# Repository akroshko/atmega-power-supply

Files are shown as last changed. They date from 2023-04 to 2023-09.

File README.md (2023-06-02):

A Variable-Voltage Constant-Current ATMega-based Power Supply
=============================================================

This project is a challenge to myself to build the best
variable-voltage constant-current power supply I could based on
ubiquitous components such as the LM317 voltage regulator, LM358 or
ATMega328 microcontroller.

The design is loosely based off of
[https://www.youtube.com/playlist?list=PLBF35875F73B5C9B5](https://www.youtube.com/playlist?list=PLBF35875F73B5C9B5)
by EEVblog.  However, it uses components I cannot obtain such as the
LT3080.

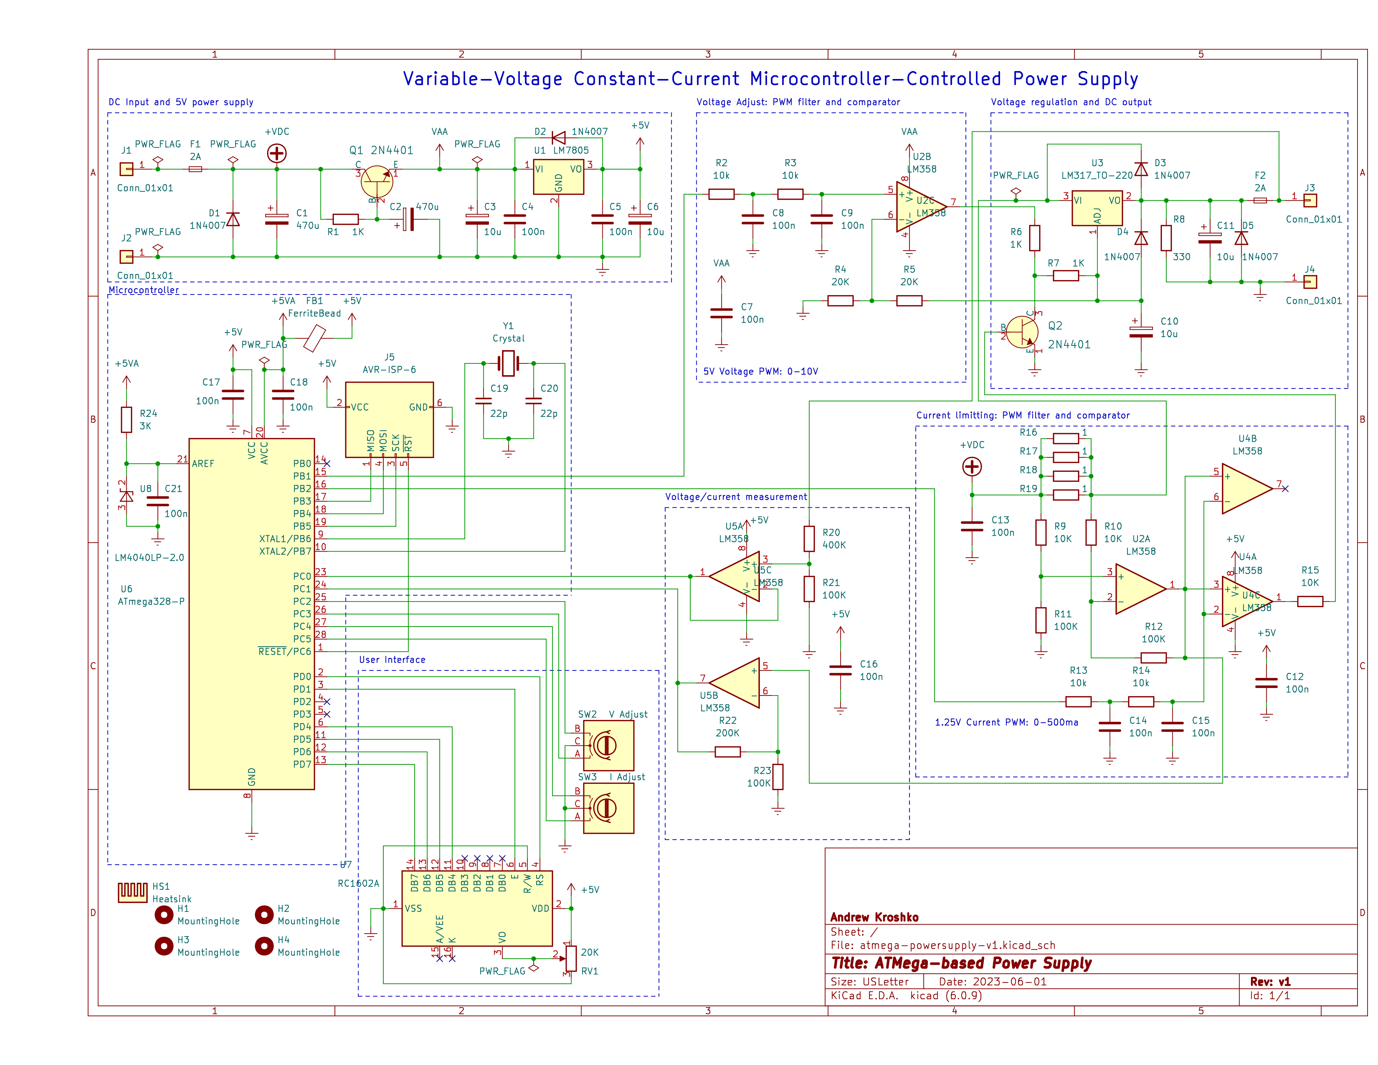
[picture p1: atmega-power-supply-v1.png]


# Things to do

I wouldn't recommend building it yourself quite yet.  There are some
issues with this design and there will be a version 1.1
at some point.

- add a photo of my prototype
- test prototype under different loads
- add a model to calibrate to in software
- use an easier-to-get LCD display
- add a bill of materials

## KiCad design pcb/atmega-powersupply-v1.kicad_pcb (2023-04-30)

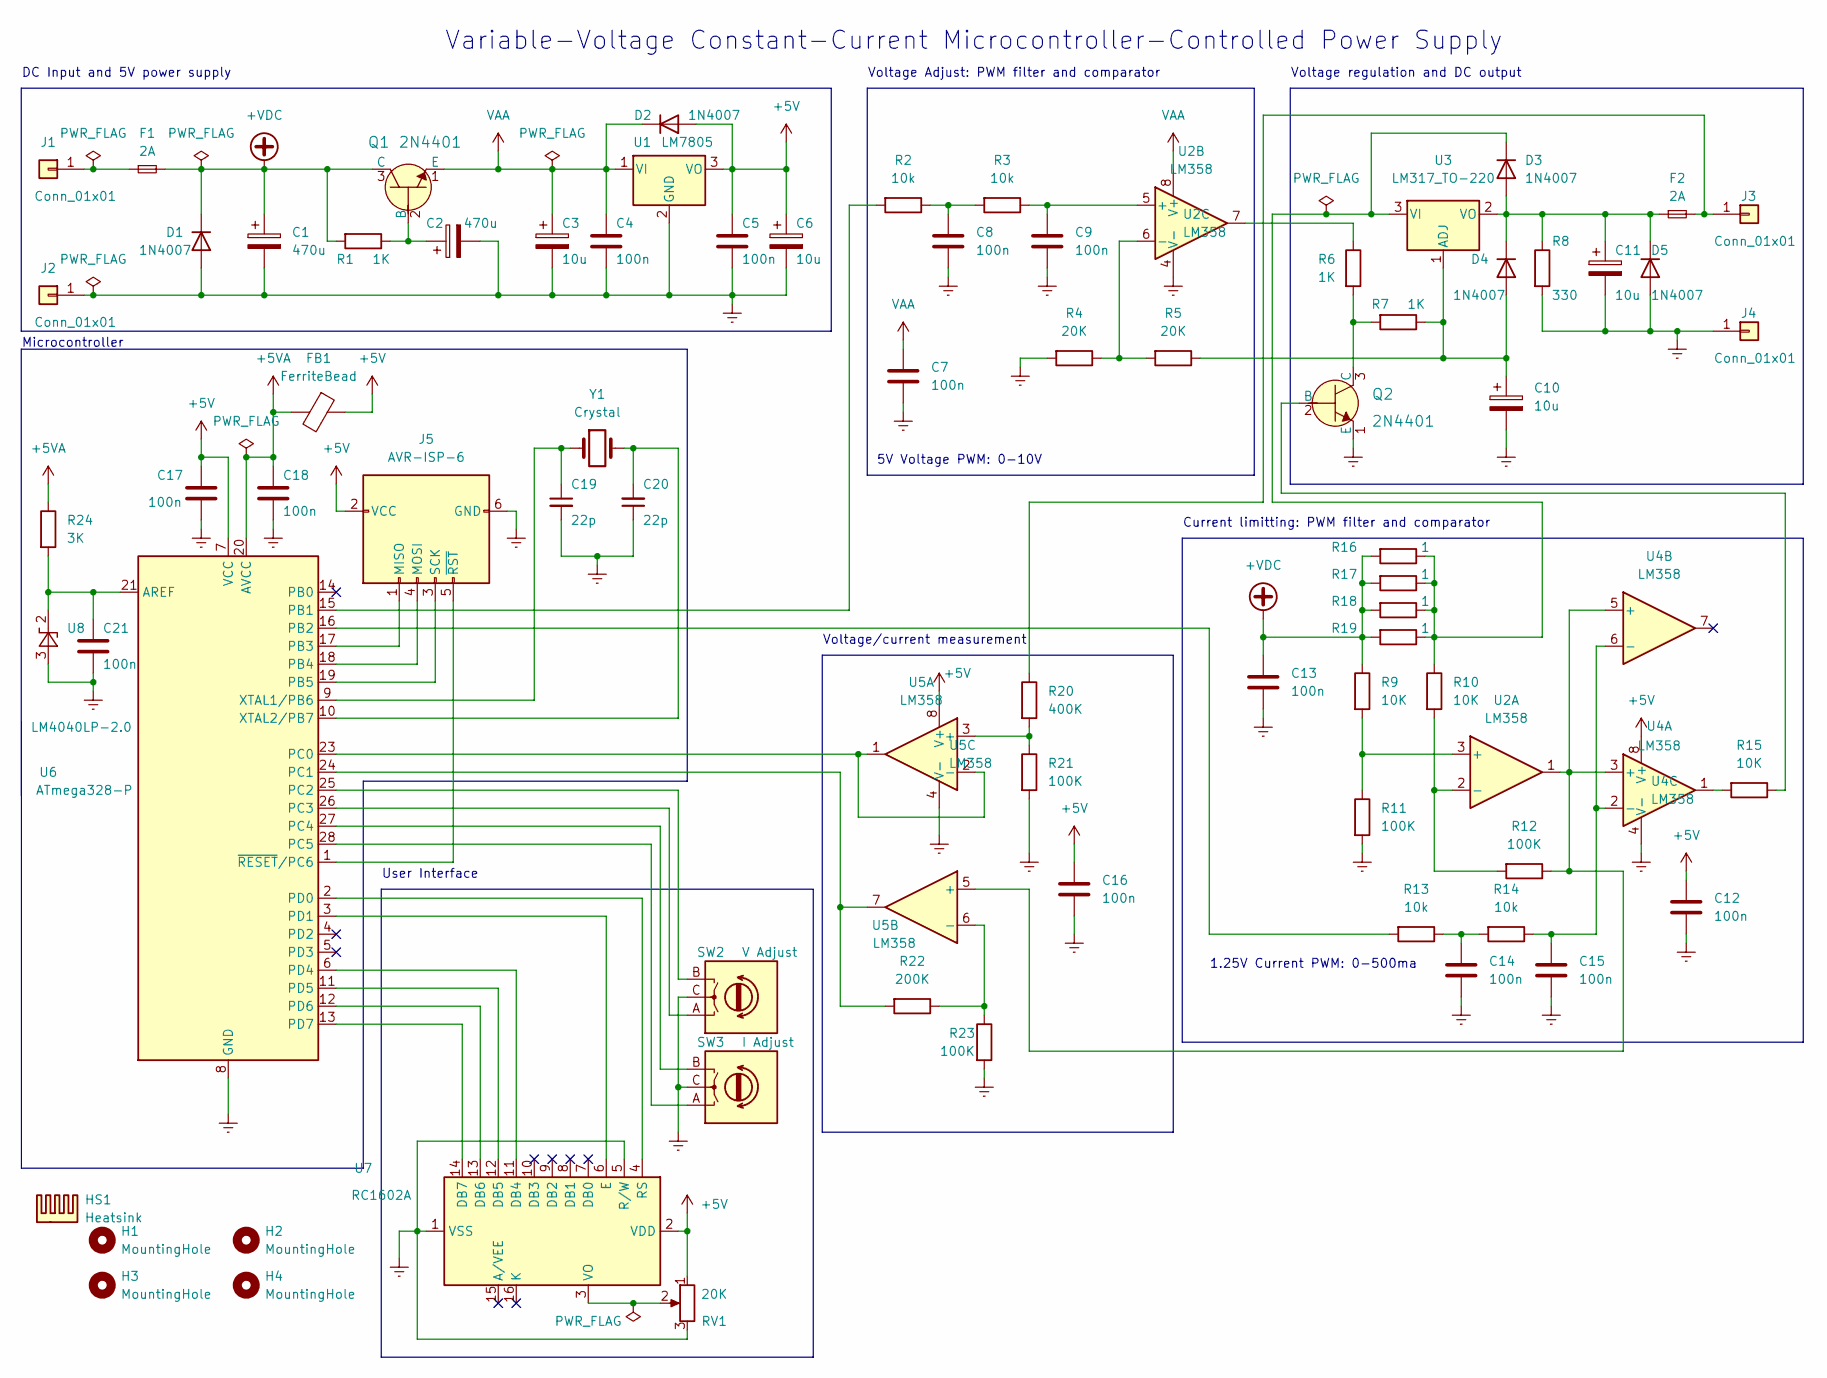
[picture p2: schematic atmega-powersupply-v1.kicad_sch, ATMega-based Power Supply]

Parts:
C1, C2: 470u; CP_Radial_D10.0mm_P5.00mm
C3, C6, C10, C11: 10u; CP_Radial_D5.0mm_P2.00mm
C4, C5, C7, C8, C9, C12, C13, C14, C15, C16, C17, C18, C21: 100n; C_Rect_L7.0mm_W2.5mm_P5.00mm
C19, C20: 22p; C_Rect_L7.0mm_W2.5mm_P5.00mm
D1, D2, D3, D4, D5: 1N4007; D_DO-41_SOD81_P10.16mm_Horizontal
F1, F2: 2A; Fuseholder_Littelfuse_100_series_5x20mm
FB1: FerriteBead; R_Axial_DIN0411_L9.9mm_D3.6mm_P12.70mm_Horizontal
H1, H2, H3, H4: MountingHole; MountingHole_4.3mm_M4
HS1: Heatsink; Heatsink_Fischer_SK104-STC-STIC_35x13mm_2xDrill2.5mm
J1, J2, J3, J4: Conn_01x01; Banana_Jack_1Pin
J5: AVR-ISP-6; PinHeader_2x03_P2.54mm_Vertical
Q1, Q2: 2N4401; TO-92L_Inline; MPN 2N4401TFR; Digi-Key_PN 2N4401D26ZCT-ND
R1, R6, R7: 1K; R_Axial_DIN0207_L6.3mm_D2.5mm_P7.62mm_Horizontal
R2, R3, R13, R14: 10k; R_Axial_DIN0207_L6.3mm_D2.5mm_P7.62mm_Horizontal
R4, R5: 20K; R_Axial_DIN0207_L6.3mm_D2.5mm_P7.62mm_Horizontal
R8: 330; R_Axial_DIN0207_L6.3mm_D2.5mm_P7.62mm_Horizontal
R9, R10, R15: 10K; R_Axial_DIN0207_L6.3mm_D2.5mm_P7.62mm_Horizontal
R11, R12, R21, R23: 100K; R_Axial_DIN0207_L6.3mm_D2.5mm_P7.62mm_Horizontal
R16, R17, R18, R19: 1; R_Axial_DIN0207_L6.3mm_D2.5mm_P7.62mm_Horizontal
R20: 400K; R_Axial_DIN0207_L6.3mm_D2.5mm_P7.62mm_Horizontal
R22: 200K; R_Axial_DIN0207_L6.3mm_D2.5mm_P7.62mm_Horizontal
R24: 3K; R_Axial_DIN0207_L6.3mm_D2.5mm_P7.62mm_Horizontal
RV1: 20K; Potentiometer_Alps_RK09L_Single_Vertical
SW2: V Adjust; RotaryEncoder_Alps_EC11E_Vertical_H20mm
SW3: I Adjust; RotaryEncoder_Alps_EC11E_Vertical_H20mm
U1: LM7805; TO-220-3_Vertical
U2, U4, U5: LM358; DIP-8_W7.62mm_Socket
U3: LM317_TO-220; TO-220-3_Vertical
U6: ATmega328-P; DIP-28_W7.62mm_Socket
U7: RC1602A
U8: LM4040LP-2.0; TO-92_Inline
Y1: Crystal; Crystal_HC50_Vertical

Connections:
+5V: C5.1, C6.1, C12.1, C16.1, C17.1, D2.2 (A), FB1.1, J5.2 (VCC), RV1.1, U1.3 (VO), U4.8 (V+), U5.8 (V+), U6.7 (VCC), U7.2 (VDD)
+5VA: C18.1, FB1.2, R24.1, U6.20 (AVCC)
+VDC: C1.1, C13.1, D1.1 (K), F1.2, Q1.3 (C), R1.2, R9.1, R16.2, R17.2, R18.2, R19.2
Earth: C1.2, C2.2, C3.2, C4.2, C5.2, C6.2, C7.2, C8.2, C9.2, C10.2, C11.2, C12.2, C13.2, C14.2, C15.2, C16.2, C17.2, C18.2, C19.2, C20.1, C21.2, D1.2 (A), D5.2 (A), J2.1, J4.1, J5.6 (GND), Q2.1 (E), R4.2, R8.2, R11.2, R21.2, R23.2, RV1.3, SW2.C, SW3.C, U1.2 (GND), U2.4 (V-), U4.4 (V-), U5.4 (V-), U6.8 (GND), U6.22 (GND), U7.1 (VSS), U7.5 (R/W), U8.3 (A)
unnamed: C2.1, Q1.2 (B), R1.1
unnamed: C8.1, R2.1, R3.2
unnamed: C9.1, R3.1, U2.5 (+)
unnamed: C10.1, D4.2 (A), R5.1, R7.1, U3.1 (ADJ)
unnamed: C11.1, D3.2 (A), D4.1 (K), D5.1 (K), F2.1, R8.1, U3.2 (VO)
unnamed: C14.1, R13.1, R14.2
unnamed: C15.1, R14.1, U4.2 (-), U4.6 (-)
unnamed: C19.1, U6.9 (XTAL1/PB6), Y1.1
unnamed: C20.2, U6.10 (XTAL2/PB7), Y1.2
unnamed: C21.1, R24.2, U6.21 (AREF), U8.2 (K)
unnamed: D3.1 (K), R10.1, R16.1, R17.1, R18.1, R19.1, U3.3 (VI)
unnamed: F1.1, J1.1
unnamed: F2.2, J3.1, R20.1
unnamed: J5.1 (MISO), U6.17 (PB3)
unnamed: J5.3 (SCK), U6.19 (PB5)
unnamed: J5.4 (MOSI), U6.18 (PB4)
unnamed: J5.5 (~RST), U6.1 (~RESET/PC6)
unnamed: Q2.2 (B), R15.1
unnamed: Q2.3 (C), R6.2, R7.2
unnamed: R2.2, U6.15 (PB1)
unnamed: R4.1, R5.2, U2.6 (-)
unnamed: R6.1, U2.7
unnamed: R10.2, R12.2, U2.2 (-)
unnamed: R9.2, R11.1, U2.3 (+)
unnamed: R12.1, U2.1, U4.3 (+), U4.5 (+), U5.5 (+)
unnamed: R13.2, U6.16 (PB2)
unnamed: R15.2, U4.1
unnamed: R20.2, R21.1, U5.3 (+)
unnamed: R22.1, R23.1, U5.6 (-)
unnamed: R22.2, U5.7, U6.24 (PC1)
unnamed: RV1.2, U7.3 (VO)
unnamed: SW2.A, U6.26 (PC3)
unnamed: SW2.B, U6.25 (PC2)
unnamed: SW3.A, U6.28 (PC5)
unnamed: SW3.B, U6.27 (PC4)
unnamed: U5.1, U5.2 (-), U6.23 (PC0)
unnamed: U6.2 (PD0), U7.4 (RS)
unnamed: U6.3 (PD1), U7.6 (E)
unnamed: U6.6 (PD4), U7.11 (DB4)
unnamed: U6.11 (PD5), U7.12 (DB5)
unnamed: U6.12 (PD6), U7.13 (DB6)
unnamed: U6.13 (PD7), U7.14 (DB7)
VAA: C3.1, C4.1, C7.1, D2.1 (K), Q1.1 (E), U1.1 (VI), U2.8 (V+)

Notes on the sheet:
Variable-Voltage Constant-Current Microcontroller-Controlled Power Supply
5V Voltage PWM: 0-10V
User Interface
Microcontroller
Voltage Adjust: PWM filter and comparator
1.25V Current PWM: 0-500ma
DC Input and 5V power supply
Current limitting: PWM filter and comparator
Voltage/current measurement
Voltage regulation and DC output

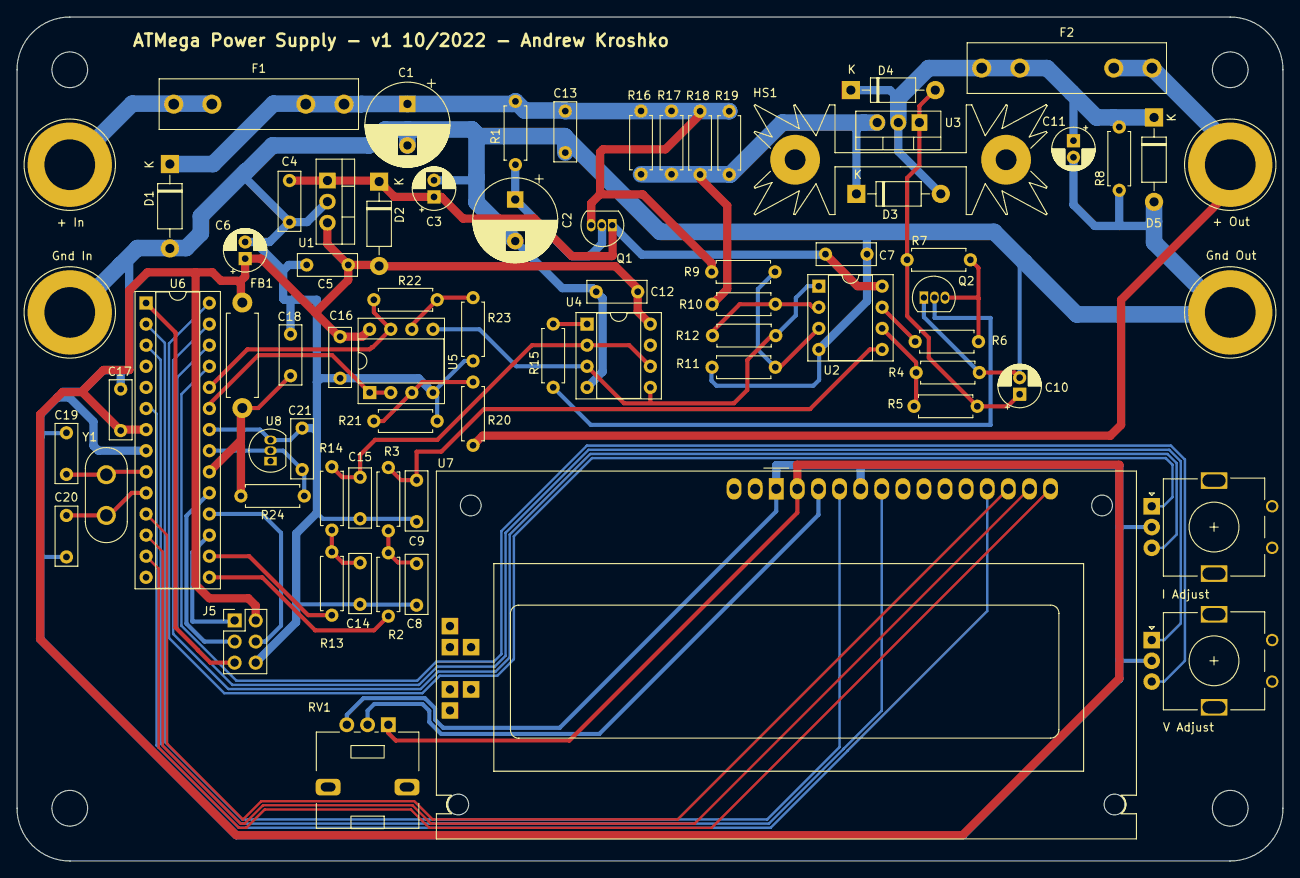
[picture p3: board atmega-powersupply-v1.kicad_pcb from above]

Board: 2 copper layers, 152.4 x 101.6 mm, 77 parts (0 on the bottom side), 47 nets.

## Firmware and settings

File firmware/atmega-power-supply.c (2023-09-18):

#include <stdlib.h>
#include <string.h>
#include <stdio.h>
#include <avr/io.h>
#define F_CPU 16000000
#include <util/delay.h>
// see for constants configurable at compile time
#include "atmega-power-supply.h"

/**
 * Initialize the port used for the LCD.
 */
void lcd_init_port () {
  DDRD |= LCD_PORT_D_DIRECTION_MASK;
}

/**
 * Functions to support the LCD display.
 *
 * Datasheet title is "Specification for LCD Module 1602A-1(V1.2)" by
 * Shenzhen Eone Electronics Co. LTD.
 *
 * Google for eone-1602a1.pdf will probably give results.
 */

/**
 * Send an instruction to the LCD.
 */
void lcd_send_instruction(unsigned char instruction) {
  PORTD = (PORTD & 0x0F) | (instruction & 0xF0);
  _delay_us(LCD_DELAY_US);
  PORTD &= ~LCD_RS;
  PORTD |=  LCD_E;
  _delay_us(LCD_DELAY_US);
  PORTD &= ~LCD_E;
  _delay_us(LCD_DELAY_SEND_US*2);
  PORTD = (PORTD & 0x0F) | (instruction << 4);
  _delay_us(LCD_DELAY_US);
  PORTD |=  LCD_E;
  _delay_us(LCD_DELAY_US);
  PORTD &= ~LCD_E;
  _delay_ms(LCD_DELAY_US*2);
}

/**
 * Send data to the LCD.
 */
void lcd_send_data(unsigned char data) {
  PORTD = (PORTD & 0x0F) | (data & 0xF0);
  _delay_us(LCD_DELAY_US);
  PORTD |=  LCD_RS;
  PORTD |=  LCD_E;
  _delay_us(LCD_DELAY_US);
  PORTD &= ~LCD_E;
  _delay_us(LCD_DELAY_SEND_US*2);
  PORTD = (PORTD & 0x0F) | (data << 4);
  _delay_us(LCD_DELAY_US);
  PORTD |=  LCD_E;
  _delay_us(LCD_DELAY_US);
  PORTD &= ~LCD_E;
  _delay_us(LCD_DELAY_SEND_US);
}

/**
 * Put LCD into 4 bit mode.
 */
void lcd_set_4bit_mode(void) {
  lcd_send_instruction(LCD_COMMAND_4bit_mode);
}

/**
 * Put LCD into 2 line mode.
 */
void lcd_2line_init(void) {
  lcd_send_instruction(LCD_COMMAND_2line_mode);
}

/**
 * Clear the LCD initially.
 */
void lcd_clear_init(void) {
  // cursor and clear
  lcd_send_instruction(0x0c);
  lcd_send_instruction(0x06);
  lcd_send_instruction(0x01);
  _delay_ms(2);
  lcd_send_instruction(0x80);
  _delay_ms(2);
}

/**
 * Move to the LCDs next line.
 */
void lcd_next_line(void) {
  lcd_send_instruction(0xC0);
}

/**
 * Clear the LCD in a non-initialization situation.
 */
void lcd_clear(void) {
  lcd_send_instruction(0x01);
  lcd_send_instruction(0x80);
}

/**
 * Move to the LCDs first line.
 */
void lcd_first_line(void) {
  lcd_send_instruction(0x83);
}

/**
 * Move to the LCDs second line.
 */
void lcd_second_line(void) {
  lcd_send_instruction(0xC3);
}

/**
 * Send string to LCD.
 */
void lcd_send_string(char *str) {
  for (int i=0; str[i] != 0; i++) {
    if (str[i] == ' ') {
      lcd_send_data(0xFE);
    } else {
      lcd_send_data(str[i]);
    }
  }
}

/**
 * Functions to support the Rottary encoder.
 *
 * There are no specific datasheets for the ones I use but search 5pin
 * rotary encoder for representative datasheets.
 */

/**
 * Initialize the rotary encoders.  See "atmega-power-supply.h"
 * descriptions of the constants.
 */
void init_rotary_encoders () {
  // set up the pins
  DDRB  |= P_PWM_V;
  DDRB  |= P_PWM_I;
  DDRC  &= ~P_ROT_V_CLK;
  PORTC |= P_ROT_V_CLK;
  DDRC  &= ~P_ROT_V_DT;
  PORTC |= P_ROT_V_DT;
  DDRC  &= ~P_ROT_I_CLK;
  PORTC |= P_ROT_I_CLK;
  DDRC  &= ~P_ROT_I_DT;
  PORTC |= P_ROT_I_DT;
}

/**
 * Get the rotary encoder position for current.
 *
 * @param i_raw                Pointer to hold the raw value for i.
 * @param i_encoder_last_state Pointer to hold the last state of the rotary encoder.
 */
void get_i_control_raw (volatile int *i_raw, volatile uint16_t *i_encoder_last_state) {
  volatile uint16_t i_current_state;
  volatile uint16_t i_current_state_2;
  i_current_state=(PINC & P_ROT_I_CLK) >> P_ROT_I_CLK_S;
  i_current_state_2=(PINC & P_ROT_I_DT) >> P_ROT_I_DT_S;
  if(i_current_state != *i_encoder_last_state) {
    if(i_current_state_2 != i_current_state) {
#if I_DIRECTION == 0
      if (*i_raw < i_full_scale) {
        (*i_raw)++;
      }
    } else {
      if (*i_raw > 0) {
        (*i_raw)--;
      }
#else
      if (*i_raw > 0) {
        (*i_raw)--;
      }
    } else {
      if ((*i_raw) < i_full_scale) {
        (*i_raw)++;
      }
#endif
    }
    OCR1B=*i_raw;
    *i_encoder_last_state = i_current_state;
  }
}

/**
 * Get the rotary encoder position for voltage.
 *
 * @param v_raw            Pointer to hold the raw value for v.
 * @param v_encoder_last_state Pointer to hold the last state of the rotary encoder.
 */
void get_v_control_raw (volatile int *v_raw, volatile uint16_t *v_encoder_last_state) {
  volatile uint16_t v_current_state;
  volatile uint16_t v_current_state_2;
  v_current_state=(PINC & P_ROT_V_CLK) >> P_ROT_V_CLK_S;
  v_current_state_2=(PINC & P_ROT_V_DT) >> P_ROT_V_DT_S;
  if(v_current_state != *v_encoder_last_state) {
    if(v_current_state_2 != v_current_state) {
#if V_DIRECTION == 0
      if (*v_raw < v_full_scale) {
        (*v_raw)++;
      }
    } else {
      if (*v_raw > 0) {
        (*v_raw)--;
      }
#else
      if (*v_raw > 0) {
        (*v_raw)--;
      }
    } else {
      if (*v_raw < v_full_scale) {
        (*v_raw)++;
      }
#endif
    }
    OCR1A=*v_raw;
    *v_encoder_last_state = v_current_state;
  }
}

/*
 * Convert raw current limit values to an actual floating point value.
 *
 * @param raw The raw value.
 * @return The actual value.
 */
float raw_to_current_limit (uint16_t raw) {
  float fraction = 5.0 * ((float)raw/(float)1024);
  float current_limit=(fraction*5.0/10.0);
  return current_limit;
}

/*
 * Convert raw voltage values to an actual floating point value.
 *
 * @param raw The raw value.
 * @return The actual value.
 */
float raw_to_voltage (uint16_t raw) {
  float fraction_voltage = 5.0 * ((float)raw/(float)1024);
  float regulated_voltage=(2.0*fraction_voltage)+1.25;
  return regulated_voltage;
}

/**
 * Inititialize the PWM.
 */
void init_pwm() {
  // should set up as 10 bit phase correct PWM
  TCCR1A=_BV(COM1A1) | _BV(COM1B1) | _BV(WGM11) | _BV(WGM10);
  TCCR1B=_BV(CS10) | _BV(WGM12) | _BV(CS10);
  OCR1A=INITIAL_V;
  OCR1B=INITIAL_I;
}

/**
 * Inititialize the A/D convertor.
 */
void init_ad () {
#ifndef DEBUG_TEMPERATURE_SENSOR
  ADMUX &= 0;
#else
  ADMUX &= (1<<REFS1) | (1<<REFS0) | (1<<MUX2);
#endif
  ADCSRA |= (1<<ADEN) | (1<<ADPS2) | (1<<ADPS1) | (1<<ADPS0);
}

/**
 * Read a value from the A/D convertor.
 *
 * @param channel The A/D channel to read from.
 */
uint16_t read_ad (uint8_t channel) {
  volatile uint16_t adc_value;
#ifndef DEBUG_TEMPERATURE_SENSOR
  ADMUX = (ADMUX & 0xF0) | (channel & 0x0F);
#else
  // temperature sensor is channel 8 on ATMEGA328/168
  ADMUX = (ADMUX & 0xF0) | (8 & 0x0F);
#endif
  ADCSRA |= (1<<ADSC);
  while(ADCSRA & (1<<ADSC));
  _delay_us(ADC_POST_DELAY_US);
  adc_value=ADC;
  return adc_value;
}

/**
 * Convert raw data from the A/D convertor to a current value.
 *
 * @param raw The raw A/D convertor value.
 * @return The actual current value.
 */
float raw_monitor_to_current (uint16_t raw) {
  float i_monitor_v=(((float)raw/(float)MONITOR_RAW_MAX)*VREF_VALUE);
  float i_sense_v=i_monitor_v/I_SCALE_MONITOR/I_SCALE_DIFF;
  float i_monitor=i_sense_v/I_SENSE_R;
  return i_monitor;
}

/**
 * Convert raw data from the A/D convertor to a voltage value.
 *
 * @param raw The raw A/D convertor value.
 * @return The actual voltage value.
 */
float raw_monitor_to_voltage (uint16_t raw) {
  // TODO: get rid of division
  float v_monitor=(((float)raw/(float)MONITOR_RAW_MAX)*VREF_VALUE)/V_SCALE;
  return v_monitor;
}


int main(void) {
  volatile int i_control_raw = INITIAL_I;
  volatile int v_control_raw = INITIAL_V;

  volatile uint16_t i_encoder_control_last_state;
  volatile uint16_t v_encoder_control_last_state;

  volatile int i_control_raw_last=-1;
  volatile int v_control_raw_last=-1;

  float i_actual=-1.0;
  float v_actual=-1.0;

  float i_actual_monitor=-1.0;
  float v_actual_monitor=-1.0;

  uint16_t v_raw_monitor=0,i_raw_monitor=0;

  int loop_count=0;
  int display_update=0;

  // The following character sequence is superflous but is good for
  // putting things to test and debug
  char display_string[16];
  lcd_init_port();
  _delay_ms(50);
  lcd_set_4bit_mode();
  lcd_clear_init();
  lcd_send_string("Starting...");
  _delay_ms(3000);
  lcd_next_line();
  // this is a unique test string that makes sure floating point is working correctly
  float test_float=5.123;
  sprintf(display_string, "%.4f", test_float);
  lcd_send_string(display_string);
  _delay_ms(3000);
  init_rotary_encoders();
  init_ad();
  // initial states
  v_encoder_control_last_state = (PINC & P_ROT_V_CLK) >> P_ROT_V_CLK_S;
  i_encoder_control_last_state = (PINC & P_ROT_I_CLK) >> P_ROT_I_CLK_S;
  init_pwm();
  // done the LCD initialization
  // finally clear out the LCD display
  lcd_clear();
  // add the I and V
  lcd_send_string("A: ");
  lcd_next_line();
  lcd_send_string("V: ");
  // first line
  lcd_first_line();
  i_actual=raw_to_current_limit(INITIAL_I);
#ifndef DEBUG_RAW
  sprintf(display_string,"%02.3fA %04d",i_actual,INITIAL_I);
#else
  sprintf(display_string,"%04d %04d",INITIAL_I,INITIAL_I);
#endif
  lcd_send_string(display_string);
  // second line
  lcd_second_line();
  v_actual=raw_to_voltage(INITIAL_V);
#ifndef DEBUG_RAW
  sprintf(display_string,"%02.3fV %04d",v_actual,INITIAL_V);
#else
  sprintf(display_string,"%04d %04d",INITIAL_V,INITIAL_V);
#endif
  lcd_send_string(display_string);

  // the main loop
  while (1) {
    // loop skip is necessary here until the rotary encoders are on
    // interupts
    if (loop_count > AD_LOOP_SKIP) {
      v_raw_monitor=read_ad(0);
      v_actual_monitor=raw_monitor_to_voltage(v_raw_monitor);
      _delay_us(ADC_POST_DELAY_US);
      // ADC channel 1 (current)
      i_raw_monitor=read_ad(1);
      i_actual_monitor=raw_monitor_to_current(i_raw_monitor);
      _delay_us(ADC_POST_DELAY_US);
      // reset the loop count
      loop_count=0;
      display_update=1;
    }
    // let's count with the rotary encoder
    get_i_control_raw(&i_control_raw, &i_encoder_control_last_state);
    get_v_control_raw(&v_control_raw, &v_encoder_control_last_state);
    if (v_control_raw_last != v_control_raw || i_control_raw_last != i_control_raw || display_update==1) {
      v_control_raw_last=v_control_raw;
      i_control_raw_last=i_control_raw;
      v_actual=raw_to_voltage(v_control_raw_last);
      i_actual=raw_to_current_limit(i_control_raw_last);
      lcd_first_line();
#ifndef DEBUG_RAW
      sprintf(display_string,"%02.3f %02.3f",i_actual,i_actual_monitor);
#else
      sprintf(display_string,"%04d %04d",i_control_raw_last,i_raw_monitor);
#endif
      lcd_send_string(display_string);
      // move to second line
      lcd_second_line();
#ifndef DEBUG_RAW
      sprintf(display_string,"%02.3f %02.3f",v_actual,v_actual_monitor);
#else
      sprintf(display_string,"%04d %04d",v_control_raw_last,v_raw_monitor);
#endif
      lcd_send_string(display_string);
      display_update=0;
    }
    // a short delay to help with debouncing and other display issues
    _delay_ms(1);
    loop_count+=1;
  }
}

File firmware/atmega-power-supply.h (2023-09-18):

// includes configurables

////////////////////////////////////////////////////////////////////////////////
// Software values to adjust behaviour
//
// These might need to be adjusted based on swapping out different
// components
////////////////////////////////////////////////////////////////////////////////

// account for different brands of rotary encoders
#define V_DIRECTION 1
#define I_DIRECTION 0

// values for PWM
const int i_full_scale=256;
const int v_full_scale=1023;

#define INITIAL_I 0
#define INITIAL_V 0

// values for the monitor
const float VREF_VALUE=2.048;

const float V_SCALE=0.2;

const float I_SCALE_MONITOR=3.0;
const float I_SCALE_DIFF=10.0;
const float I_SENSE_R=0.25;

const uint16_t MONITOR_RAW_MAX=1024;

////////////////////////////////////////////////////////////////////////////////
// Arbitrary constants that can be used to tweak performance
////////////////////////////////////////////////////////////////////////////////

#define LCD_DELAY_US           1
#define LCD_DELAY_SEND_US    100
#define ADC_POST_DELAY_US     16

 // do analog to digital every 50 loops
#define AD_LOOP_SKIP          50

////////////////////////////////////////////////////////////////////////////////
// Constants that will generally only change with the changing the circuit itself
// _S indicates shift need for to access appropriate bit
// P_ designates the "pin", which actually maps to the individual pin of a partuclar port
//
// _ROT indicates rotary encoding
// _V indicates the rotary encoder that controls voltage
// _I indicates the rotary encoder that controls current
// _CLK indicates the rotary encoder clock pin
// _DT indicates the rotary encoder ??? pin
//
// LCD_ indicates the LCD

// _RS _E _DB4 _DB5 _DB6 _DB7 are all constants that are specific to
// pins on the LCD
////////////////////////////////////////////////////////////////////////////////

// PWM pins
const uint8_t P_PWM_V=(_BV(1)); // PB1
const uint8_t P_PWM_I=(_BV(2)); // PB2

// rotary encoder pins
#define P_ROT_V_CLK_S 2                         // PC2 SHIFT
const uint8_t P_ROT_V_CLK=(_BV(P_ROT_V_CLK_S)); // PC2
#define P_ROT_V_DT_S 3                          // PC3 SHIFT
const uint8_t P_ROT_V_DT=(_BV(P_ROT_V_DT_S));   // PC3
#define P_ROT_I_CLK_S 4                         // PC4 SHIFT
const uint8_t P_ROT_I_CLK=(_BV(P_ROT_I_CLK_S)); // PC4
#define P_ROT_I_DT_S 5                          // PC5 SHIFT
const uint8_t P_ROT_I_DT=(_BV(P_ROT_I_DT_S));   // PC5

// LCD pins
#define LCD_RS_S 0                      // PD0 SHIFT
const uint8_t LCD_RS=(_BV(LCD_RS_S));   // PD0
#define LCD_E_S  1                      // PD1 SHIFT
const uint8_t LCD_E=(_BV(LCD_E_S));     // PD1
#define LCD_DB4_S 4                     // PD4 SHIFT
const uint8_t LCD_DB4=(_BV(LCD_DB4_S)); // PD4
#define LCD_DB5_S 5                     // PD5 SHIFT
const uint8_t LCD_DB5=(_BV(LCD_DB5_S)); // PD5
#define LCD_DB6_S 6                     // PD6 SHIFT
const uint8_t LCD_DB6=(_BV(LCD_DB6_S)); // PD6
#define LCD_DB7_S 7                     // PD7 SHIFT
const uint8_t LCD_DB7=(_BV(LCD_DB7_S)); // PD7

const uint8_t LCD_PORT_D_DIRECTION_MASK=_BV(LCD_RS_S)|_BV(LCD_E_S)| \
                                        _BV(LCD_DB4_S)|_BV(LCD_DB5_S)| \
                                        _BV(LCD_DB6_S)|_BV(LCD_DB7_S);
// LCD commands
#define LCD_COMMAND_4bit_mode  0x02
#define LCD_COMMAND_2line_mode 0x28
// TODO: fill out more LCD commands after datasheet review

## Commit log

2023-04-30 initial commit of kicad files
    [atmega-powersupply-v1-B_Cu.gbr, atmega-powersupply-v1-B_Mask.gbr, atmega-powersupply-v1-B_Paste.gbr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]
2023-06-02 updating with more information such as improved schematic and README.md
    [atmega-powersupply-v1.kicad_sch]
2023-09-18 merged code to use A/D convertor to monitor voltage/current, general improvements and refactoring of code
